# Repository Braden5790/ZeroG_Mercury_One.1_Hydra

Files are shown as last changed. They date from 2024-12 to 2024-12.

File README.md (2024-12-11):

# ZeroG Mercury One.1 Hydra
Welcome to the configuration repository for my **Ender 5 Pro** that I converted to a **ZeroG Mercury One.1 Hydra 3D Printer**! This repository contains all the configuration files, macros, and scripts needed to run my custom setup powered by [Klipper firmware](https://www.klipper3d.org/).

The folder titled **Printer_Klipper_Configs** contains all of the configuration files that I am currently running on my 3D Printer. Most of my printer was inspired by the stock ZeroG build, except the toolhead where I use the Voron Stealthburner.

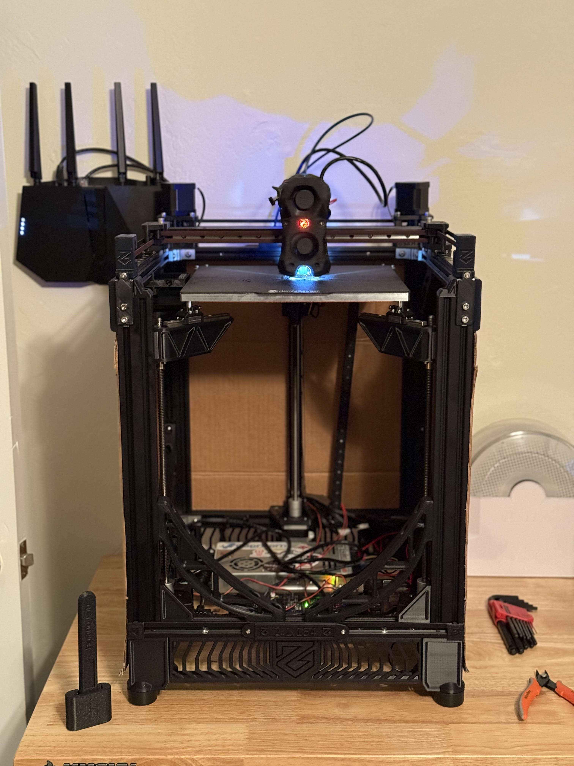
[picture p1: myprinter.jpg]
My Printer


---

## Custom Changes
- I wanted to add a nozzle wiper to my printer so I designed a nozzle wiper. This is inspired by the Bambu Lab X1 Carbon poop chute using the A1 wiper. The macro for it can be found in `macros.cfg`.

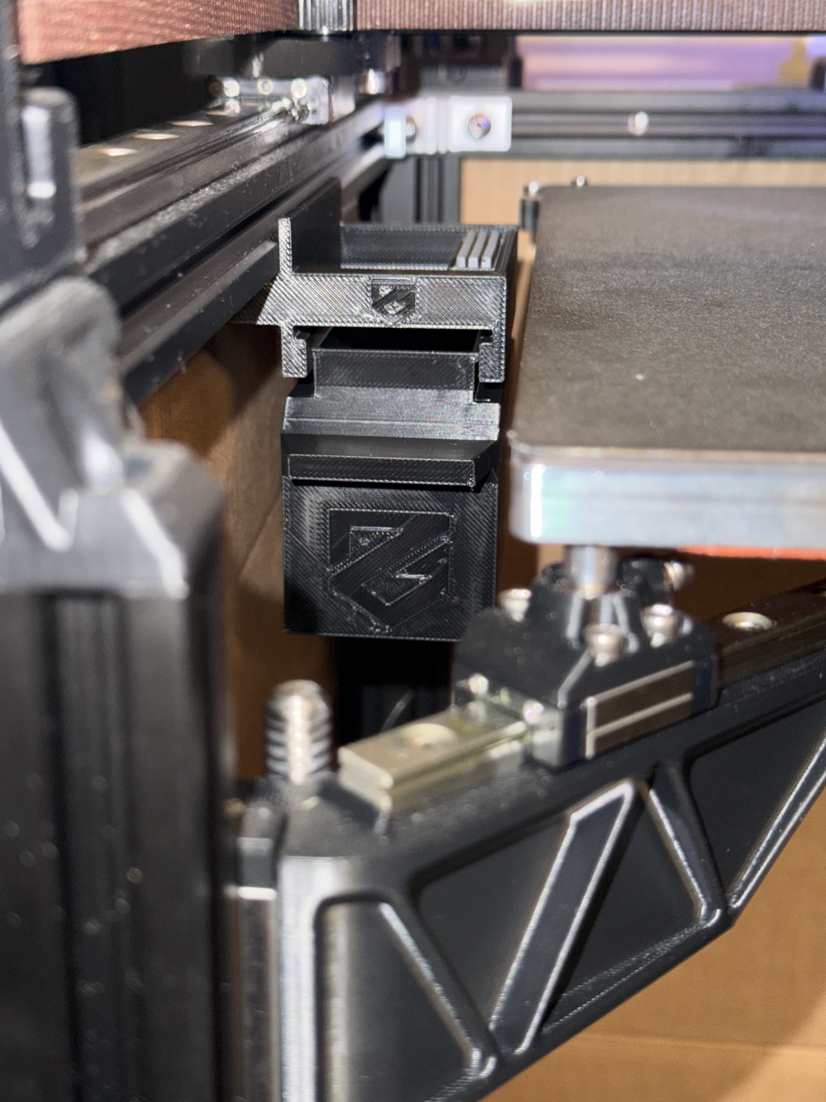
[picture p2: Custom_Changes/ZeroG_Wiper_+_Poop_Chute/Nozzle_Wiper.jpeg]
Nozzle Wiper


**Nozzle Wiper In Action:**

Nozzle Wiper In Action (https://www.youtube.com/shorts/vOTouopDlZY)

- Created a gusset plate for the top of my printer so I could remove the top front bar and maintain some rigidity.

---

## Contents of Note

- `Custom_Changes`: Folder containing all of the custom 3D Printed parts that I used for this build.
- `printer.cfg`: Main configuration file for the printer.
- `macros.cfg`: Custom macros to enhance functionality.
- `KAMP_Settings.cfg`: [Klipper Adaptive Meshing & Purging](https://github.com/kyleisah/Klipper-Adaptive-Meshing-Purging)

---

## Features

- **Mercury One.1 CoreXY Design**: Optimized for high-speed and high-accuracy printing.
- **Hydra Bed System**: Voron Trident style bed motion system.
- **Klipper Firmware**: Advanced firmware with macro scripting and precise control.
- **Custom Macros**: Streamlined commands for easy operation.
- **Tuned Profiles**: Configurations optimized for my setup, including PID tuning and pressure advance.

---

## Notes

These configurations are specific to my hardware setup and may need adjustments for your build. Refer to the Klipper documentation for detailed information on configuration options.

---

## Acknowledgements

Thanks to the ZeroG team for their incredible design and thanks to the Klipper community for their support.

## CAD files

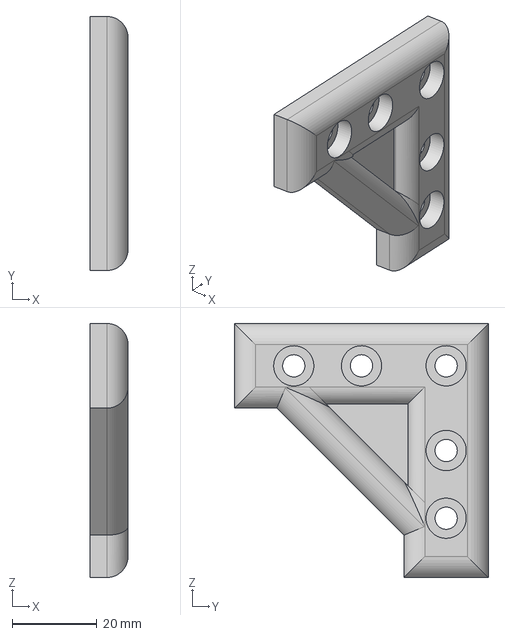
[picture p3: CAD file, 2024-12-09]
Custom_Changes/Corner_Gusset_Plate.step
9.00 x 60.0 x 60.0 mm

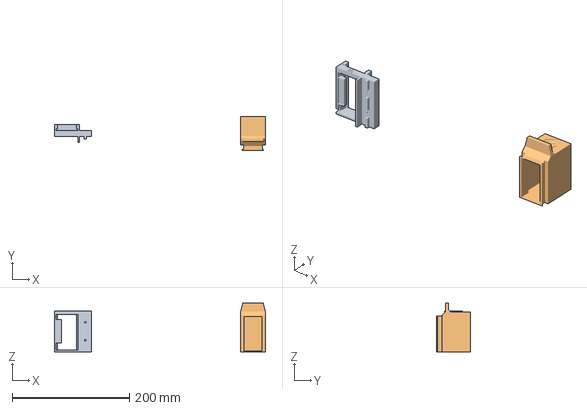
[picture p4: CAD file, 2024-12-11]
Custom_Changes/ZeroG_Wiper_+_Poop_Chute/Zero G Mercury One.1 Nozzle Wiper Mount + Poop Chute.3mf
359.9 x 57.3 x 83.0 mm
Zero G Mercury One.1 Nozzle Wiper Mount v6.step
Zero G Mercury One.1 Nozzle Wiper Poop Chute v5.step

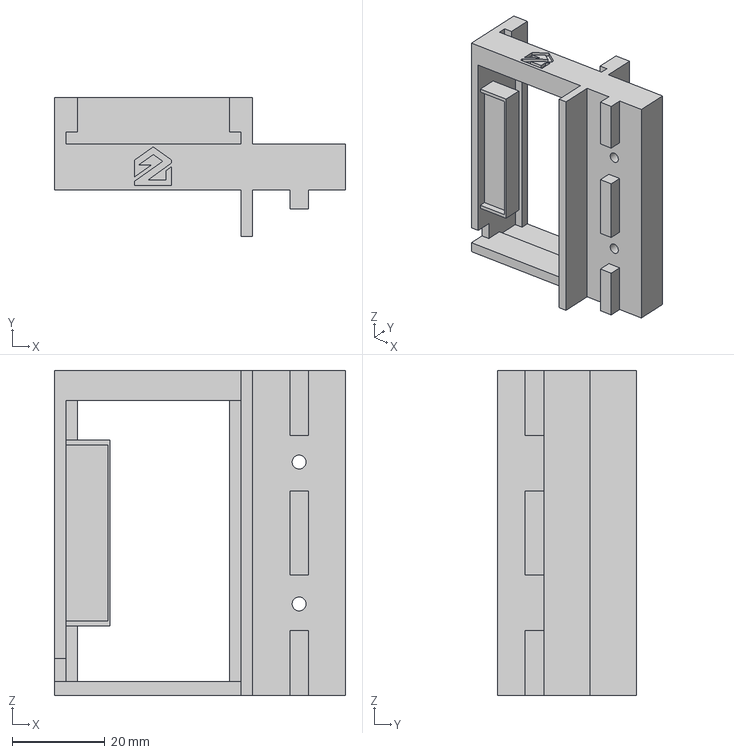
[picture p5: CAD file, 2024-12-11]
Custom_Changes/ZeroG_Wiper_+_Poop_Chute/Zero G Mercury One.1 Nozzle Wiper Mount v6.step
62.7 x 30.0 x 70.0 mm

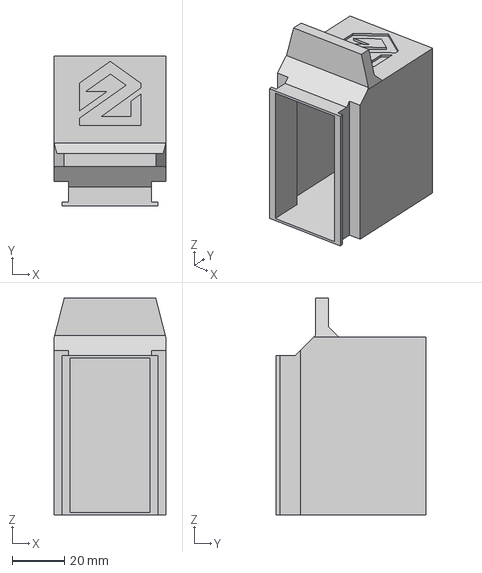
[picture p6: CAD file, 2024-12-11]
Custom_Changes/ZeroG_Wiper_+_Poop_Chute/Zero G Mercury One.1 Nozzle Wiper Poop Chute v5.step
42.7 x 57.3 x 83.0 mm

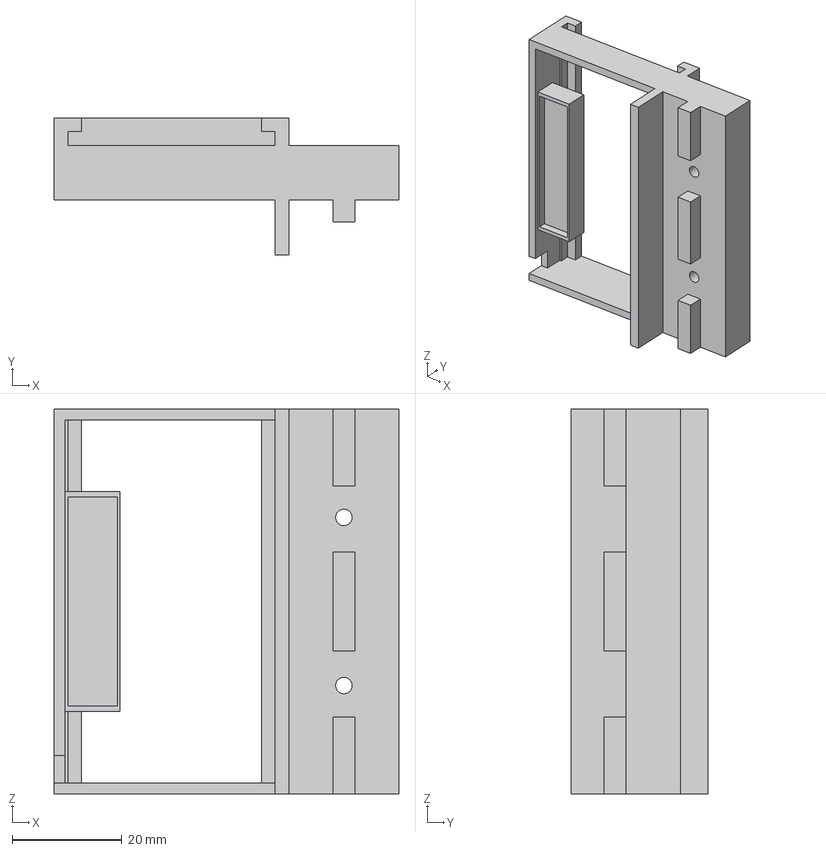
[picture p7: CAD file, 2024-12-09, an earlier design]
Custom_Changes/ZeroG_Wiper_+_Poop_Chute/Zero G Mercury One.1 Nozzle Wiper Mount v4.step
62.7 x 25.0 x 70.0 mm

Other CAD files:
Custom_Changes/ZeroG_Wiper_+_Poop_Chute/Zero G Mercury One.1 Nozzle Wiper Poop Chute v4.step
Custom_Changes/ZeroG_Wiper_+_Poop_Chute/Zero G Mercury One.1 Nozzle Wiper Mount v5.step
Custom_Changes/ZeroG_Wiper_+_Poop_Chute/Zero G Mercury One.1 Nozzle Wiper Poop Chute v3.step
Custom_Changes/ZeroG_Wiper_+_Poop_Chute/Zero G Mercury One.1 Nozzle Wiper Mount v6.stl
Custom_Changes/ZeroG_Wiper_+_Poop_Chute/Zero G Mercury One.1 Nozzle Wiper Poop Chute v5.stl

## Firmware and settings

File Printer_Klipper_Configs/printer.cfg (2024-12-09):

[include mainsail.cfg]
[include KAMP_Settings.cfg]
[include stealthburner_leds.cfg]
[include macros.cfg]
#[include Zerog_Purge.cfg]

#####################################################################
# 	General Setup
#####################################################################

[printer]
kinematics: corexy
max_velocity: 300 #600
max_accel: 3000 #5000
max_z_velocity: 5
max_z_accel: 50

# Enable object exclusion
[exclude_object]

# Enable arcs support
[gcode_arcs]
resolution: 0.1

[respond]

[virtual_sdcard]
path: ~/printer_data/gcodes
on_error_gcode: CANCEL_PRINT

[mcu]
canbus_uuid: eda556af8838
#canbus_interface: can0

[mcu EBBCan]
canbus_uuid: 7beb2bc5841d
#canbus_interface: can0

#[firmware_retraction]
#retract_length: 40
#retract_speed: 40
#unretract_extra_length: 10 # Increase if not primed enough when starting, decrease if over primed
#unretract_speed: 25

#####################################################################
# 	X & Y Steppers
#####################################################################

# X Stepper on Motor1(B Motor)
[stepper_x]
step_pin: PE2
dir_pin: !PB4
enable_pin: !PC11
microsteps: 16
rotation_distance: 40
full_steps_per_rotation: 200
endstop_pin: ~EBBCan: gpio24
position_min: -12.0
position_endstop: 282.5
position_max: 282.5
homing_speed: 25
homing_retract_dist: 5
homing_positive_dir: true

[tmc2209 stepper_x]
uart_pin: PC10
interpolate: True
run_current: 0.8
sense_resistor: 0.110
stealthchop_threshold: 0

# Y Stepper on Motor2 (A Motor)
[stepper_y]
step_pin: PF12
dir_pin: !PF11
enable_pin: !PB3
microsteps: 16
rotation_distance: 40
full_steps_per_rotation: 200
endstop_pin: ^PF4
position_min: 0
position_endstop: 250
position_max: 250
homing_speed: 25
homing_retract_dist: 5
homing_positive_dir: true

[tmc2209 stepper_y]
uart_pin: PF13
interpolate: True
run_current: 0.8
sense_resistor: 0.110
stealthchop_threshold: 0

#####################################################################
# 	Z Steppers
#####################################################################

# Z0 Stepper - Front Left on MOTOR3_A
[stepper_z]
step_pin: PD7
dir_pin: !PD6
enable_pin: !PF10
rotation_distance: 2    
microsteps: 128
endstop_pin: probe:z_virtual_endstop
position_max: 265
position_min: -2
homing_speed: 8.0
second_homing_speed: 3
homing_retract_dist: 3

[tmc2209 stepper_z]
uart_pin: PF9
run_current: 0.580
stealthchop_threshold: 999999

#	Z1 Stepper - Rear  on Motor5
[stepper_z1]
step_pin: PD3
dir_pin: !PD2
enable_pin: !PD5
rotation_distance: 2  
microsteps: 128

[tmc2209 stepper_z1]
uart_pin: PD4
interpolate: true
run_current: 0.580
stealthchop_threshold: 999999

#	Z2 Stepper - Front Right on Motor6
[stepper_z2]
step_pin: PC9
dir_pin: !PC8
enable_pin: !PD1
rotation_distance: 2 
microsteps: 128

[tmc2209 stepper_z2]
uart_pin: PD0
interpolate: true
run_current: 0.580
stealthchop_threshold: 999999

#####################################################################
# 	Extruder
#####################################################################

[extruder]
step_pin: EBBCan: gpio18
dir_pin: EBBCan: gpio19
enable_pin: !EBBCan: gpio17
microsteps: 16
rotation_distance: 46.565
gear_ratio: 9:1
nozzle_diameter: 0.400
filament_diameter: 1.750
heater_pin: EBBCan: gpio7
sensor_type: MAX31865
sensor_pin: EBBCan: gpio9
spi_software_sclk_pin: EBBCan: gpio10
spi_software_mosi_pin: EBBCan: gpio8
spi_software_miso_pin: EBBCan: gpio11
rtd_nominal_r: 1000
rtd_reference_r: 4300
rtd_num_of_wires: 2
min_temp: 1
max_temp: 300
max_power: 1.0
min_extrude_temp: 1
max_extrude_cross_section: 5

[tmc2209 extruder]
uart_pin: EBBCan: gpio20
interpolate: false
run_current: 0.6
stealthchop_threshold: 0

#####################################################################
# 	Bed Heater
#####################################################################

[heater_bed]
heater_pin: PB5 
sensor_type: NTC 100K MGB18-104F39050L32
sensor_pin: PA0
min_temp: 0
max_temp: 130

#####################################################################
# 	Probe,  Bed Mesh, & Homing
#####################################################################

[probe]
pin: ^!EBBCan: gpio22
x_offset: 0
y_offset: 0
#z_offset: 0
speed: 2.0
samples: 3
samples_result: median
sample_retract_dist: 3.0
samples_tolerance: 0.008
samples_tolerance_retries: 3

# Tap Activate GCode
activate_gcode:
    {% set PROBE_TEMP = 100 %}
    {% set MAX_TEMP = PROBE_TEMP + 5 %}
    {% set ACTUAL_TEMP = printer.extruder.temperature %}
    {% set TARGET_TEMP = printer.extruder.target %}

    {% if TARGET_TEMP > PROBE_TEMP %}
        { action_respond_info('Extruder temperature target of %.1fC is too high, lowering to %.1fC' % (TARGET_TEMP, PROBE_TEMP)) }
        M109 S{ PROBE_TEMP }
    {% else %}
        # Temperature target is already low enough, but nozzle may still be too hot.
        {% if ACTUAL_TEMP > MAX_TEMP %}
            { action_respond_info('Extruder temperature %.1fC is still too high, waiting until below %.1fC' % (ACTUAL_TEMP, MAX_TEMP)) }
            TEMPERATURE_WAIT SENSOR=extruder MAXIMUM={ MAX_TEMP }
        {% endif %}
    {% endif %}

[bed_mesh]
speed: 200
horizontal_move_z: 5
mesh_min: 10, 0
mesh_max: 260, 250
probe_count: 5, 5
adaptive_margin: 5

[idle_timeout]
timeout: 1800

[safe_z_home]
home_xy_position: 135.5, 125
speed: 100
z_hop: 10

[z_tilt]
z_positions: # Location of bed pivot points
    -50, 18
    125, 298
    300, 18
points: # Back Middle, Front Left, Front Right # Probing Points
    135.5, 250
    8, 0
    263, 0
speed: 200
horizontal_move_z: 5
retries: 5
retry_tolerance: 0.0075

#####################################################################
# 	Resonance Compensation
#####################################################################

[adxl345]
cs_pin: EBBCan: gpio1
spi_software_sclk_pin: EBBCan: gpio2
spi_software_mosi_pin: EBBCan: gpio0
spi_software_miso_pin: EBBCan: gpio3
axes_map: z,-y,x

[resonance_tester]
probe_points: 135.5, 125, 20
accel_chip: adxl345

#####################################################################
# 	Sensors
#####################################################################

[temperature_sensor EBB_2209] #EBB_NTC
sensor_type: Generic 3950
sensor_pin: EBBCan: gpio28

##[filament_motion_sensor encoder_sensor]
##detection_length: 7
#   The minimum length of filament pulled through the sensor to trigger
#   a state change on the switch_pin
#   Default is 7 mm.
##extruder: extruder
#   The name of the extruder section this sensor is associated with.
#   This parameter must be provided.
##switch_pin: PC5
# changing the switch_pin name according to your motherboard
#pause_on_runout: True
##runout_gcode: FILAMENT_RUNOUT
#insert_gcode:
#event_delay:
#pause_delay:

#####################################################################
# 	Fan Control
#####################################################################

#	Part Cooling Fan
[fan]
pin: EBBCan: gpio13
kick_start_time: 0.5
off_below: 0.10

#	Hotend Fan
[heater_fan hotend_fan]
pin: EBBCan: gpio14
max_power: 1
kick_start_time: 0.5
heater: extruder
heater_temp: 50.0

# MCU Fan
[temperature_fan Manta_M8P]
pin: PE0
max_power: 0.60
control: watermark
max_delta: 2
sensor_type: temperature_mcu
min_temp: 10
max_temp: 80
target_temp: 20
shutdown_speed: 0.0

# CB1 Fan
[temperature_fan CB1]
pin: PC12
max_power: 0.60
control: watermark
max_delta: 2
sensor_type: temperature_host
min_temp: 10
max_temp: 80
target_temp: 20
shutdown_speed: 0.0

#*# <---------------------- SAVE_CONFIG ---------------------->
#*# DO NOT EDIT THIS BLOCK OR BELOW. The contents are auto-generated.
#*#
#*# [extruder]
#*# control = pid
#*# pid_kp = 22.197
#*# pid_ki = 2.084
#*# pid_kd = 59.098
#*#
#*# [heater_bed]
#*# control = pid
#*# pid_kp = 48.146
#*# pid_ki = 2.058
#*# pid_kd = 281.652
#*#
#*# [probe]
#*# z_offset = -0.430
#*#
#*# [bed_mesh default]
#*# version = 1
#*# points =
#*# 	-0.034219, 0.018594, 0.045312, 0.025078, -0.005625, -0.050391
#*# 	-0.027422, 0.019219, 0.037500, 0.021562, -0.006016, -0.055781
#*# 	-0.053516, 0.014375, 0.007969, -0.011172, -0.027891, -0.053516
#*# 	-0.089844, -0.035938, -0.027891, -0.023594, -0.048594, -0.070703
#*# 	-0.125078, -0.075625, -0.048281, -0.029844, -0.062500, -0.089141
#*# 	-0.134922, -0.077344, -0.049688, -0.035938, -0.042734, -0.051172
#*# x_count = 6
#*# y_count = 6
#*# mesh_x_pps = 2
#*# mesh_y_pps = 2
#*# algo = lagrange
#*# tension = 0.2
#*# min_x = 30.0
#*# max_x = 245.0
#*# min_y = 30.0
#*# max_y = 235.0
#*#
#*# [input_shaper]
#*# shaper_type_x = zv
#*# shaper_freq_x = 85.8
#*# shaper_type_y = mzv
#*# shaper_freq_y = 67.0

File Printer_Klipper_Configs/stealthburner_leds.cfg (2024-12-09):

# Macros for setting the status leds on the Voron StealthBurner toolhead (or for any neopixel-type leds).
#
# You will need to configure a neopixel (or other addressable led, such as dotstar). See
# https://www.klipper3d.org/Config_Reference.html#neopixel for configuration details.


#####################################
#           INSTRUCTIONS            #
#####################################
# How to use all this stuff:
#
#     1.  Copy this .cfg file into your Klipper config directory and then add [include stealthburner_leds.cfg]
#         to the top of your printer.cfg in order to register the LEDs and macros with Klipper.
#     2.  Define your LEDs by editing [neopixel sb_leds] below and entering the data pin from your control board
#         as well as the color order.
#
#           Note: RGB and RGBW are different and must be defined explicitly.  RGB and RGBW are also not able to 
#                 be mix-and-matched in the same chain. A separate data line would be needed for proper functioning.
#
#                 RGBW LEDs will have a visible yellow-ish phosphor section to the chip.  If your LEDs do not have
#                 this yellow portion, you have RGB LEDs.
#
#     3.  Save your config and restart Klipper.
#
#           Note: We set RED and BLUE to 1.0 to make it easier for users and supporters to detect 
#                 misconfigurations or miswiring. The default color format is for Neopixels with a dedicated 
#                 white LED. On startup, all three SB LEDs should light up.
#
#                 If you get random colors across your LEDs, change the color_order to GRB and restart. Then
#                 omit the W for each suggested color_order in the next paragraph.
#
#                 If you get MAGENTA, your  color order is correct. If you get CYAN, you need to use RGBW. If
#                 you get YELLOW, you need to use BRGW (note that BRG is only supported in the latest Klipper
#                 version).
#
#     4.  Once you have confirmed that the LEDs are set up correctly, you must now decide where you want 
#         these macros called up...which means adding them to your existing gcode macros.  NOTHING will happen
#         unless you add the STATUS_????? macros to your existing gcode macros.  
#
#           Example: add STATUS_LEVELING to the beginning of your QGL gcode macro, and then add STATUS_READY 
#                    to the end of it to set the logo LED and nozzle LEDs back to the `ready` state.
#
#           Example: add STATUS_CLEANING to the beginning of your nozzle-cleaning macro, and then STATUS_READY
#                    to the end of it to return the LEDs back to `ready` state.
#
#     5.  Feel free to change colors of each macro, create new ones if you have a need to.  The macros provided below
#         are just an example of what is possible.  If you want to try some more complex animations, you will most
#         likely have to use WLED with Moonraker and a small micro-controller 
#
#####################################
#       END INSTRUCTRUCTIONS        #
#####################################


[neopixel sb_leds]
pin: EBBCan: gpio16
#   The pin connected to the neopixel. This parameter must be provided.
chain_count: 3
#   The number of Neopixel chips that are "daisy chained" to the
#   provided pin. The default is 1 (which indicates only a single
#   Neopixel is connected to the pin).
color_order: GRBW
#   Set the pixel order required by the LED hardware. Options are GRB,
#   RGB, GRBW, or RGBW. The default is GRB.
initial_RED: 1.0
initial_GREEN: 1.0
initial_BLUE: 1.0
initial_WHITE: 1.0
#   Sets the initial LED color of the Neopixel. Each value should be
#   between 0.0 and 1.0. The WHITE option is only available on RGBW
#   LEDs. The default for each color is 0.#

[delayed_gcode setdisplayneopixel]
initial_duration: 1
gcode:
       SET_LED LED=sb_leds RED=0 GREEN=1 BLUE=0.129 INDEX=1 TRANSMIT=0
       SET_LED LED=sb_leds RED=1 GREEN=1 BLUE=1 WHITE=1 INDEX=2 TRANSMIT=0
       SET_LED LED=sb_leds RED=1 GREEN=1 BLUE=1 WHITE=1 INDEX=3

# Most configuration for the macros can be done by modifying the variables in the _sb_vars macro
# at the start of this file.

##########
# MACROS #
##########

# The following status macros are available (these go inside of your macros):
#
#    STATUS_READY
#    STATUS_OFF
#    STATUS_BUSY
#    STATUS_HEATING
#    STATUS_LEVELING
#    STATUS_HOMING
#    STATUS_CLEANING
#    STATUS_MESHING
#    STATUS_CALIBRATING_Z
#
# With additional macros for basic control:
#
#    SET_NOZZLE_LEDS_ON
#    SET_LOGO_LEDS_OFF
#    SET_NOZZLE_LEDS_OFF
#
# Contributed by Voron discord users wile.e, Tetsunosuke, and etherwalker


[gcode_macro _sb_vars]
# User settings for the StealthBurner status leds. You can change the status colors and led
# configurations for the logo and nozzle here.
variable_colors: {
        'logo': { # Colors for logo states
            'busy': {'r': 0.4, 'g': 0.0, 'b': 0.0, 'w': 0.0},
            'cleaning': {'r': 0.0, 'g': 0.02, 'b': 0.5, 'w': 0.0},
            'calibrating_z': {'r': 0.8, 'g': 0., 'b': 0.35, 'w': 0.0},
            'heating': {'r': 0.3, 'g': 0.18, 'b': 0.0, 'w': 0.0},
            'homing': {'r': 0.0, 'g': 0.6, 'b': 0.2, 'w': 0.0},
            'leveling': {'r': 0.5, 'g': 0.1, 'b': 0.4, 'w': 0.0},
            'meshing': {'r': 0.2, 'g': 1.0, 'b': 0.0, 'w': 0.0},
            'off': {'r': 0.0, 'g': 0.0, 'b': 0.0, 'w': 0.0},
            'printing': {'r': 1.0, 'g': 0.0, 'b': 0.0, 'w': 0.0},
            'standby': {'r': 0.0, 'g': 1.0, 'b': 0.0, 'w': 0.1},
            'white': {'r': 1.0, 'g': 1.0, 'b': 1.0, 'w': 1.0},
        },
        'nozzle': { # Colors for nozzle states
            'heating': {'r': 0.8, 'g': 0.35, 'b': 0.0, 'w':0.0},
            'off': {'r': 0.0, 'g': 0.0, 'b': 0.0, 'w': 0.0},
            'on': {'r': 0.8, 'g': 0.8, 'b': 0.8, 'w':1.0},
            'standby': {'r': 0.6, 'g': 0.0, 'b': 0.0, 'w':0.0},
        },
        'thermal': {
            'hot': {'r': 1.0, 'g': 0.0, 'b': 0.0, 'w': 0.0},
            'cold': {'r': 0.3, 'g': 0.0, 'b': 0.3, 'w': 0.0}
        }
    }
variable_logo_led_name:         "sb_leds" 
# The name of the addressable LED chain that contains the logo LED(s)
variable_logo_idx:              "1" 
# A comma-separated list of indexes LEDs in the logo
variable_nozzle_led_name:       "sb_leds"
# The name of the addressable LED chain that contains the nozzle LED(s). This will
# typically be the same LED chain as the logo.
variable_nozzle_idx:            "2,3"
# A comma-separated list of indexes of LEDs in the nozzle
gcode:
    # This section is required.  Do Not Delete.


[gcode_macro _set_sb_leds]
gcode:
    {% set red = params.RED|default(0)|float %}
    {% set green = params.GREEN|default(0)|float %}
    {% set blue = params.BLUE|default(0)|float %}
    {% set white = params.WHITE|default(0)|float %}
    {% set led = params.LED|string %}
    {% set idx = (params.IDX|string).split(',') %}
    {% set transmit_last = params.TRANSMIT|default(1) %}

    {% for led_index in idx %}
        {% set transmit=transmit_last if loop.last else 0 %}
        set_led led={led} red={red} green={green} blue={blue} white={white} index={led_index} transmit={transmit}
    {% endfor %}

[gcode_macro _set_sb_leds_by_name]
gcode:
    {% set leds_name = params.LEDS %}
    {% set color_name = params.COLOR %}
    {% set color = printer["gcode_macro _sb_vars"].colors[leds_name][color_name] %}
    {% set led = printer["gcode_macro _sb_vars"][leds_name + "_led_name"] %}
    {% set idx = printer["gcode_macro _sb_vars"][leds_name + "_idx"] %}
    {% set transmit = params.TRANSMIT|default(1) %}

    _set_sb_leds led={led} red={color.r} green={color.g} blue={color.b} white={color.w} idx="{idx}" transmit={transmit}

[gcode_macro _set_logo_leds]
gcode:
    {% set red = params.RED|default(0)|float %}
    {% set green = params.GREEN|default(0)|float %}
    {% set blue = params.BLUE|default(0)|float %}
    {% set white = params.WHITE|default(0)|float %}
    {% set led = printer["gcode_macro _sb_vars"].logo_led_name %}
    {% set idx = printer["gcode_macro _sb_vars"].logo_idx %}
    {% set transmit=params.TRANSMIT|default(1) %}

    _set_sb_leds led={led} red={red} green={green} blue={blue} white={white} idx="{idx}" transmit={transmit}

[gcode_macro _set_nozzle_leds]
gcode:
    {% set red = params.RED|default(0)|float %}
    {% set green = params.GREEN|default(0)|float %}
    {% set blue = params.BLUE|default(0)|float %}
    {% set white = params.WHITE|default(0)|float %}
    {% set led = printer["gcode_macro _sb_vars"].nozzle_led_name %}
    {% set idx = printer["gcode_macro _sb_vars"].nozzle_idx %}
    {% set transmit=params.TRANSMIT|default(1) %}

    _set_sb_leds led={led} red={red} green={green} blue={blue} white={white} idx="{idx}" transmit={transmit}

[gcode_macro set_logo_leds_off]
gcode:
    {% set transmit=params.TRANSMIT|default(1) %}
    _set_logo_leds red=0 blue=0 green=0 white=0 transmit={transmit}
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

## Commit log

2024-12-09 Update and rename Corner_Gusset_Plate.step to Custom_Changes/Corner_Gusset_Plate.step
    [Corner_Gusset_Plate.step]
2024-12-10 Update and rename Custom_Changes/Zero G Mercury One.1 Nozzle Wiper Mount v4.step to Custom_Changes/ZeroG_Wiper_+_Poop_Chute/Zero G Mercury One.1 Nozzle Wiper Mount v4.step
    [Zero G Mercury One.1 Nozzle Wiper Mount v4.step]
2024-12-10 Update and rename Custom_Changes/Zero G Mercury One.1 Nozzle Wiper Poop Chute v3.step to Custom_Changes/ZeroG_Wiper_+_Poop_Chute/Zero G Mercury One.1 Nozzle Wiper Poop Chute v3.step
    [Zero G Mercury One.1 Nozzle Wiper Poop Chute v3.step]
2024-12-11 Rename Nozzle Wipe.mp4 to Nozzle_Wipe.mp4
2024-12-11 Rename Nozzle Wiper.jpeg to Nozzle_Wiper.jpeg
